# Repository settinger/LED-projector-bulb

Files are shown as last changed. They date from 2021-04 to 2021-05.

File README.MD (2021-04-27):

# LED Replacement for DCA Lamps

In the era of film, the [DCA lamp](https://www.replacementlightbulbs.com/lampdca21v150w.html) was used in dozens of styles of home projector. Nowadays, they are quite hard to come by. And even if you do find a supplier, you'll still end up paying upwards of $100 USD for a single bulb that only lasts around 15 hours! Some people have modified their film projectors to use modern LED illumination, but this usually requires an alternate external power supply and some permanent modifications to the vintage machine. My vision is something much simpler: an LED circuit shaped like the original bulb, a true drop-in replacement!

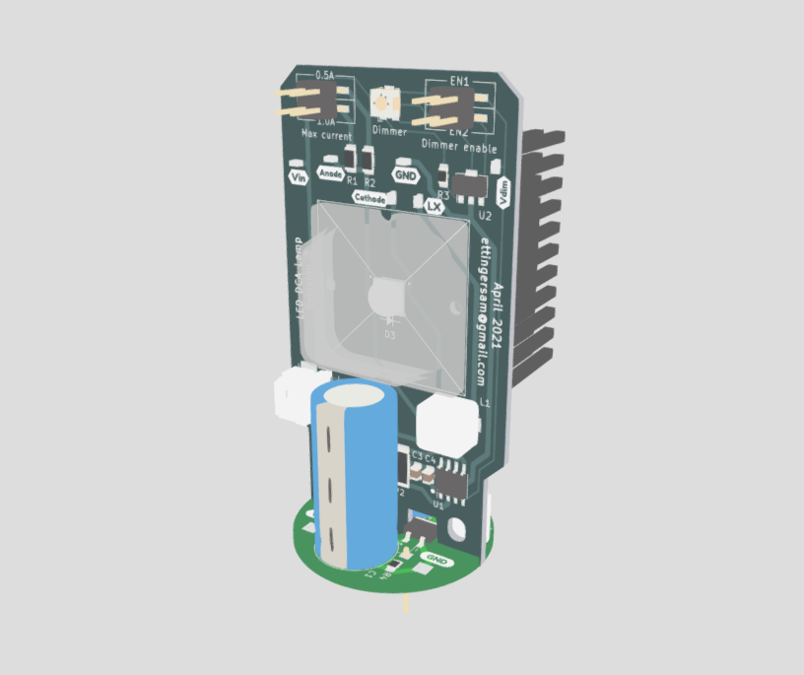
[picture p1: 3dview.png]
3D render of LED bulb
[ <br/>*(Click to go to an interactive 3D viewer)*](https://skfb.ly/onLyB)<br/>

This is most definitely still a work-in-progress. Message me with questions/advice/suggestions/anything!

## Latest version: revision 3 (April 2021)

This is a significant change from the previous two versions. It uses a 19W Cree XHP50.2 (or XHP50) LED, and the whole upright PCB is now a single-layer aluminum-substrate PCB for better thermal management. Screw terminals are used to affix the two boards perpendicularly, and some safety features (2.5A fuse and an optional inrush current limiter) have been added. The bill of materials can be found [over here](/bom/bom.md) or in [this interactive page](/bom/ibom.html).

## Revision 2 (April 2021)
The main change between revisions 1 and 2 is the LED driver itself. I switched from the AL8860 IC to the PAM2863 because the AL8860 is out of stock friggin' EVERYWHERE right now. I also did away with the 15V LDO; why did I even put that on there in the first place? In its place is a tiny 3.3V LDO to power the dimmer controls. This design still uses the same LED module. I did not fix the incorrect light center distance. Instead, I overhauled the PCB to make Revision 3.

## Revision 1 (November 2020)
My first attempt at a DCA replacement. It uses a no-brand 10W LED module that is (was?) prevalent on eBay. The AC-to-DC rectifying capacitors are 16 mm in diameter, and protrude over the edge of the base PCB. This prevented them from sitting properly in my test projector (an Argos Showmaster 750A). Even if it were to fit in the socket, the light center distance on this PCB is a 1/4 inch too high, which is substantial. The dimming circuit did not behave the way I was expecting; at low control voltages the LED would flash on and off around 0.5 Hz, instead of getting dimmer.

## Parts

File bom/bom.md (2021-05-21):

# Bill of Materials
## Revision 3

## Base PCB BOM

| | References | Value | Footprint | Quantity | Digi-Key Part Number | Notes |
|---|---|---|---|---|---|---|
| 1 | R4 | 1 MΩ | 0805 (2012 Metric) | 1 | [RMCF0805JT1M20CT-ND‎](https://www.digikey.com/product-detail/en/RMCF0805JT1M20/RMCF0805JT1M20CT-ND/2418504/) | |
| 2 | JP1 | 0 Ω | 0603 (1608 Metric) | 1 | [36-5110CT-ND‎](https://www.digikey.com/product-detail/en/5110/36-5110CT-ND/5118858/) | Rated for at least 3 A. Do not use if you are using an inrush current limiter (TH1). |
| 3 | C1, C2 | 1000 μF | ⌀ 12.5 mm, 5 mm pitch | 1 | [UHD1V102MHD-ND‎](https://www.digikey.com/product-detail/en/UHD1V102MHD/UHD1V102MHD-ND/2428131/) | Rated for at least 1.5 A ripple current; must be less than 25.4 mm high to accommodate the lens and heatsink. |
| 4 | D1 | Bridge Rectifier | TO-269AA | 1 | [641-1432-1-ND‎](https://www.digikey.com/product-detail/en/CDBHM2100L-HF/641-1432-1-ND/2731390/) | I<sub>F(AV)</sub> ≥ 2 A, V<sub>RRM</sub> ≥ 40 V. |
| 5 | F1 | 2.5 A Slow Blow | 1206 (3216 Metric) | 1 | [507-1895-1-ND‎](https://www.digikey.com/product-detail/en/0685T2500-01/507-1895-1-ND/4968176/) | I've never had to pick a fuse for an AC load before, I have very little confidence in this fuse selection. |
| 6 | LA1 | Lamp base | GX17q | 1 | | It's just four header pins. |
| 7 | J1, J2 | Molex CLIK-Mate 1.50 mm Cable Assembly | Off-board | 0.5 | [WM22838-ND‎](https://www.digikey.com/product-detail/en/0151350203/WM22838-ND/6833464/) | Cut cable assembly in half, solder bare wires to J1 and J2 on base PCB, plug the connector into J3. |
| 8 | H1, H2 | Würth Redcube Screw Terminal | 7.0×4.3 mm | 2 | [732-10897-1-ND](https://www.digikey.com/en/products/detail/w%C3%BCrth-elektronik/7466313R/6643993) | |
| 9 | TH1 | 5 Ω 5 A NTC Thermistor | Off-board | 1 | [495-2100-ND‎](https://www.digikey.com/product-detail/en/B57237S0509M000/495-2100-ND/739855/) | Inrush current limiter, might not be necessary. Do not solder JP1 if you plan to use TH1. |
| 10 | *[no designator]* | M3 bolt, 6mm length | Off-board | 2 | | Attaches upright PCB at terminals H1, H2. |

## Upright PCB BOM

| | References | Value | Footprint | Quantity | Digi-Key Part Number | Notes |
|---|---|---|---|---|---|---|
| 1 | R1 | 0.100 Ω | 1206 (3216 Metric) | 1 | [273-KDV12FR100ETCT-ND‎](https://www.digikey.com/product-detail/en/KDV12FR100ET/273-KDV12FR100ETCT-ND/10476942/) | |
| 2 | R2 | 0.200 Ω | 1206 (3216 Metric) | 1 | [273-KDV12FR200ETCT-ND‎](https://www.digikey.com/product-detail/en/KDV12FR200ET/273-KDV12FR200ETCT-ND/10477106/) | |
| 3 | R3 | 7.5 kΩ | 0805 (2012 Metric) | 1 | [2019-RK73H2ATTD7501FCT-ND‎](https://www.digikey.com/product-detail/en/RK73H2ATTD7501F/2019-RK73H2ATTD7501FCT-ND/10235459/) | |
| 4 | JP2 | 0 Ω | 2512 (6432 Metric) | 1 | [CR2512-J/-000ELFCT-ND‎](https://www.digikey.com/product-detail/en/CR2512-J%2f-000ELF/CR2512-J%2f-000ELFCT-ND/3767855/) | Rated for at least 2 A. |
| 5 | C3, C4 | 10 μF | 0805 (2012 Metric) | 2 | [490-10515-1-ND‎](https://www.digikey.com/product-detail/en/GRM21BR6YA106ME43L/490-10515-1-ND/5026446/) | |
| 6 | C5 | 1 μF | 0805 (2012 Metric) | 1 | [1276-2926-1-ND‎](https://www.digikey.com/product-detail/en/CL21B105KAFNFNE/1276-2926-1-ND/3891012/?itemSeq=362829291) | Optional capacitor to smooth output ripple. |
| 7 | L1 | 47 μH | 7.4×7.0 mm | 1 | [P124172CT-ND‎](https://www.digikey.com/product-detail/en/ETQ-P4M470KFM/P124172CT-ND/9765177/?itemSeq=362633496) | Any value between 33 μH and 120 μH should be fine. |
| 8 | RV1 | 10 kΩ | TC33X | 1 | [TC33X-103ECT-ND‎](https://www.digikey.com/product-detail/en/TC33X-2-103E/TC33X-103ECT-ND/612911/) | |
| 9 | D2 | LED | 2020 (5050 Metric) | 1 | [XHP50B-00-0000-0D0BJ250ECT-ND‎](https://www.digikey.com/product-detail/en/XHP50B-00-0000-0D0BJ250E/XHP50B-00-0000-0D0BJ250ECT-ND/6612923/) (cool white) or [XHP50A-00-0000-0D0HG430HCT-ND‎](https://www.digikey.com/product-detail/en/XHP50A-00-0000-0D0HG430H/XHP50A-00-0000-0D0HG430HCT-ND/5806086/) (warm white) | Cree XHP50 or XHP50.2 White LED. |
| 10 | D3 | Schottky 3 A 40 V | SOD-123W | 1 | [1655-1591-1-ND‎](https://www.digikey.com/product-detail/en/SK34ATR/1655-1591-1-ND/6023036/) | |
| 11 | U1 | PAM2863 | SOIC-8 Exposed Pad | 1 | [PAM2863ECRDICT-ND‎](https://www.digikey.com/product-detail/en/PAM2863ECR/PAM2863ECRDICT-ND/4505228/) | [Datasheet](https://www.diodes.com/assets/Datasheets/PAM2863.pdf) |
| 12 | U2 | AP7381-33Y-13 | SOT-89-3 (TO-243AA)| 1 | [AP7381-33Y-13DICT-ND‎](https://www.digikey.com/product-detail/en/AP7381-33Y-13/AP7381-33Y-13DICT-ND/7914856/) | Ensure the regulator is rated to handle more than 30 V input. |
| 13 | J3 | Molex CLIK-Mate 2-position | 1.50 mm pitch | 1 | [WM14459CT-ND‎](https://www.digikey.com/product-detail/en/5025840260/WM14459CT-ND/6133190/) | The footprint should work for vertical- or horizontal-insert sockets. |
| 14 | J4, J5 | 2x2 SMD Pin Header | SMD 2.52 mm pitch  | 2 | [WM9514-ND‎](https://www.digikey.com/product-detail/en/0015912040/WM9514-ND/3124153/) | |
| 15 | HS1 | Heatsink | 35×35×18 mm | 1 | [HS396-ND‎](https://www.digikey.com/product-detail/en/374724B00032G/HS396-ND/1216400/) | How big should it be? Do I need a fan? |
| 16 | TP1, TP2, TP3, TP4, TP5, TP6 | Test Point | 0603 (1608 Metric) | 6 | [2019-RCUCTECT-ND‎](https://www.digikey.com/product-detail/en/RCUCTE/2019-RCUCTECT-ND/11476593/) | Optional. |
| 17 | LENS1 | LEDiL Lens HB-SQ-W | 25×25 mm | 1 | [711-1589-ND‎](https://www.digikey.com/product-detail/en/C16369_HB-SQ-W/711-1589-ND/9095514/) | Is this necessary? Who knows. |
| 18 | *[no designator]* | 2.54 mm pin header shunts  | Off-board | 4 | [609-861410021H11LF-ND‎](https://www.digikey.com/product-detail/en/861410021H11LF/609-861410021H11LF-ND/4417821/) | Used for setting the max current (J4) and enabling the dimmer function (J5). |

## Combined BOM

| | References | Value | Footprint | Quantity | Digi-Key Part Number | Notes |
|---|---|---|---|---|---|---|
| 1 | R1 | 0.100 Ω | 1206 (3216 Metric) | 1 | [273-KDV12FR100ETCT-ND‎](https://www.digikey.com/product-detail/en/KDV12FR100ET/273-KDV12FR100ETCT-ND/10476942/) | |
| 2 | R2 | 0.200 Ω | 1206 (3216 Metric) | 1 | [273-KDV12FR200ETCT-ND‎](https://www.digikey.com/product-detail/en/KDV12FR200ET/273-KDV12FR200ETCT-ND/10477106/) | |
| 3 | R3 | 7.5 kΩ | 0805 (2012 Metric) | 1 | [2019-RK73H2ATTD7501FCT-ND‎](https://www.digikey.com/product-detail/en/RK73H2ATTD7501F/2019-RK73H2ATTD7501FCT-ND/10235459/) | |
| 4 | R4 | 1 MΩ | 0805 (2012 Metric) | 1 | [RMCF0805JT1M20CT-ND‎](https://www.digikey.com/product-detail/en/RMCF0805JT1M20/RMCF0805JT1M20CT-ND/2418504/) | |
| 5 | JP1 | 0 Ω | 0603 (1608 Metric) | 1 | [36-5110CT-ND‎](https://www.digikey.com/product-detail/en/5110/36-5110CT-ND/5118858/) | Rated for at least 3 A. Do not use if you are using an inrush current limiter (TH1). |
| 6 | JP2 | 0 Ω | 2512 (6432 Metric) | 1 | [CR2512-J/-000ELFCT-ND‎](https://www.digikey.com/product-detail/en/CR2512-J%2f-000ELF/CR2512-J%2f-000ELFCT-ND/3767855/) | Rated for at least 2 A. |
| 7 | C1, C2 | 1000 μF | ⌀ 12.5 mm, 5 mm pitch | 1 | [UHD1V102MHD-ND‎](https://www.digikey.com/product-detail/en/UHD1V102MHD/UHD1V102MHD-ND/2428131/) | Rated for at least 1.5 A ripple current; must be less than 25.4 mm high to accommodate the lens and heatsink. |
| 8 | C3, C4 | 10 μF | 0805 (2012 Metric) | 2 | [490-10515-1-ND‎](https://www.digikey.com/product-detail/en/GRM21BR6YA106ME43L/490-10515-1-ND/5026446/) | |
| 9 | C5 | 1 μF | 0805 (2012 Metric) | 1 | [1276-2926-1-ND‎](https://www.digikey.com/product-detail/en/CL21B105KAFNFNE/1276-2926-1-ND/3891012/?itemSeq=362829291) | Optional capacitor to smooth output ripple. |
| 10 | L1 | 47 μH | 7.4×7.0 mm | 1 | [P124172CT-ND‎](https://www.digikey.com/product-detail/en/ETQ-P4M470KFM/P124172CT-ND/9765177/?itemSeq=362633496) | Any value between 33 μH and 120 μH should be fine. |
| 11 | RV1 | 10 kΩ | TC33X | 1 | [TC33X-103ECT-ND‎](https://www.digikey.com/product-detail/en/TC33X-2-103E/TC33X-103ECT-ND/612911/) | |
| 12 | D1 | Bridge Rectifier | TO-269AA | 1 | [641-1432-1-ND‎](https://www.digikey.com/product-detail/en/CDBHM2100L-HF/641-1432-1-ND/2731390/) | I<sub>F(AV)</sub> ≥ 2 A, V<sub>RRM</sub> ≥ 40 V. |
| 13 | D2 | LED | 2020 (5050 Metric) | 1 | [XHP50B-00-0000-0D0BJ250ECT-ND‎](https://www.digikey.com/product-detail/en/XHP50B-00-0000-0D0BJ250E/XHP50B-00-0000-0D0BJ250ECT-ND/6612923/) (cool white) or [XHP50A-00-0000-0D0HG430HCT-ND‎](https://www.digikey.com/product-detail/en/XHP50A-00-0000-0D0HG430H/XHP50A-00-0000-0D0HG430HCT-ND/5806086/) (warm white) | Cree XHP50 or XHP50.2 White LED. |
| 14 | D3 | Schottky 3 A 40 V | SOD-123W | 1 | [1655-1591-1-ND‎](https://www.digikey.com/product-detail/en/SK34ATR/1655-1591-1-ND/6023036/) | |
| 15 | F1 | 2.5 A Slow Blow | 1206 (3216 Metric) | 1 | [507-1895-1-ND‎](https://www.digikey.com/product-detail/en/0685T2500-01/507-1895-1-ND/4968176/) | I've never had to pick a fuse for an AC load before, I have very little confidence in this fuse selection. |
| 16 | U1 | PAM2863 | SOIC-8 Exposed Pad | 1 | [PAM2863ECRDICT-ND‎](https://www.digikey.com/product-detail/en/PAM2863ECR/PAM2863ECRDICT-ND/4505228/) | [Datasheet](https://www.diodes.com/assets/Datasheets/PAM2863.pdf) |
| 17 | U2 | AP7381-33Y-13 | SOT-89-3 (TO-243AA)| 1 | [AP7381-33Y-13DICT-ND‎](https://www.digikey.com/product-detail/en/AP7381-33Y-13/AP7381-33Y-13DICT-ND/7914856/) | Ensure the regulator is rated to handle more than 30 V input. |
| 18 | LA1 | Lamp base | GX17q | 1 | | It's just four header pins. |
| 19 | J1, J2 | Molex CLIK-Mate 1.50 mm Cable Assembly | Off-board | 0.5 | [WM22838-ND‎](https://www.digikey.com/product-detail/en/0151350203/WM22838-ND/6833464/) | Cut cable assembly in half, solder bare wires to J1 and J2 on base PCB, plug the connector into J3. |
| 20 | J3 | Molex CLIK-Mate 1.50 mm 2-position socket | 8.5×8.0 mm | 1 | [WM14459CT-ND‎](https://www.digikey.com/product-detail/en/5025840260/WM14459CT-ND/6133190/) | The footprint should work for vertical- or horizontal-insert sockets. |
| 21 | J4, J5 | 2x2 SMD Pin Header | SMD 2.52 mm pitch  | 2 | [WM9514-ND‎](https://www.digikey.com/product-detail/en/0015912040/WM9514-ND/3124153/) | |
| 22 | H1, H2 | Würth Redcube Screw Terminal | 7.0×4.3 mm | 2 | [732-10897-1-ND](https://www.digikey.com/en/products/detail/w%C3%BCrth-elektronik/7466313R/6643993) | |
| 23 | HS1 | Heatsink | 35×35×18 mm | 1 | [HS396-ND‎](https://www.digikey.com/product-detail/en/374724B00032G/HS396-ND/1216400/) | How big should it be? Do I need a fan? |
| 24 | TP1, TP2, TP3, TP4, TP5, TP6 | Test Point | 0603 (1608 Metric) | 6 | [2019-RCUCTECT-ND‎](https://www.digikey.com/product-detail/en/RCUCTE/2019-RCUCTECT-ND/11476593/) | Optional. |
| 25 | LENS1 | LEDiL Lens HB-SQ-W | 25×25 mm | 1 | [711-1589-ND‎](https://www.digikey.com/product-detail/en/C16369_HB-SQ-W/711-1589-ND/9095514/) | Is this necessary? Who knows. |
| 26 | TH1 | 5 Ω 5 A NTC Thermistor | Off-board | 1 | [495-2100-ND‎](https://www.digikey.com/product-detail/en/B57237S0509M000/495-2100-ND/739855/) | Inrush current limiter, might not be necessary. Do not solder JP1 if you plan to use TH1. |
| 27 | *[no designator]* | M3 bolt, 6 mm length | Off-board | 2 | | Attaches upright PCB at terminals H1, H2. |
| 28 | *[no designator]* | 2.54 mm pin header shunts  | Off-board | 4 | [609-861410021H11LF-ND‎](https://www.digikey.com/product-detail/en/861410021H11LF/609-861410021H11LF-ND/4417821/) | Used for setting the max current (J4) and enabling the dimmer function (J5). |

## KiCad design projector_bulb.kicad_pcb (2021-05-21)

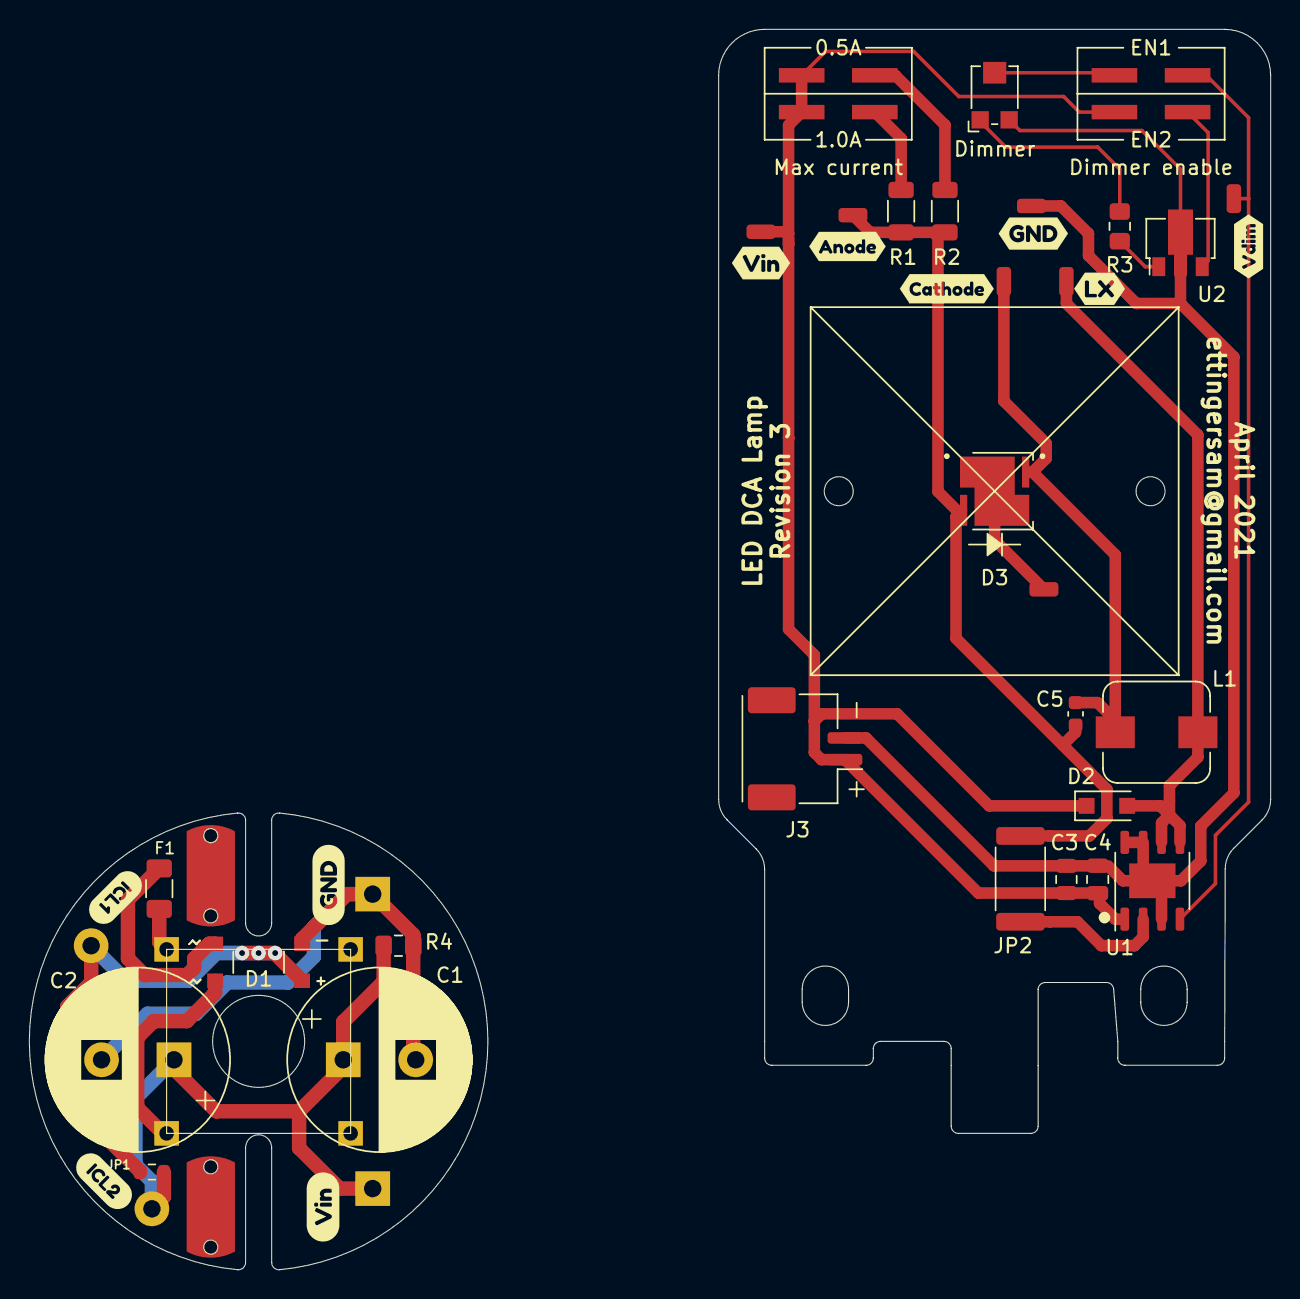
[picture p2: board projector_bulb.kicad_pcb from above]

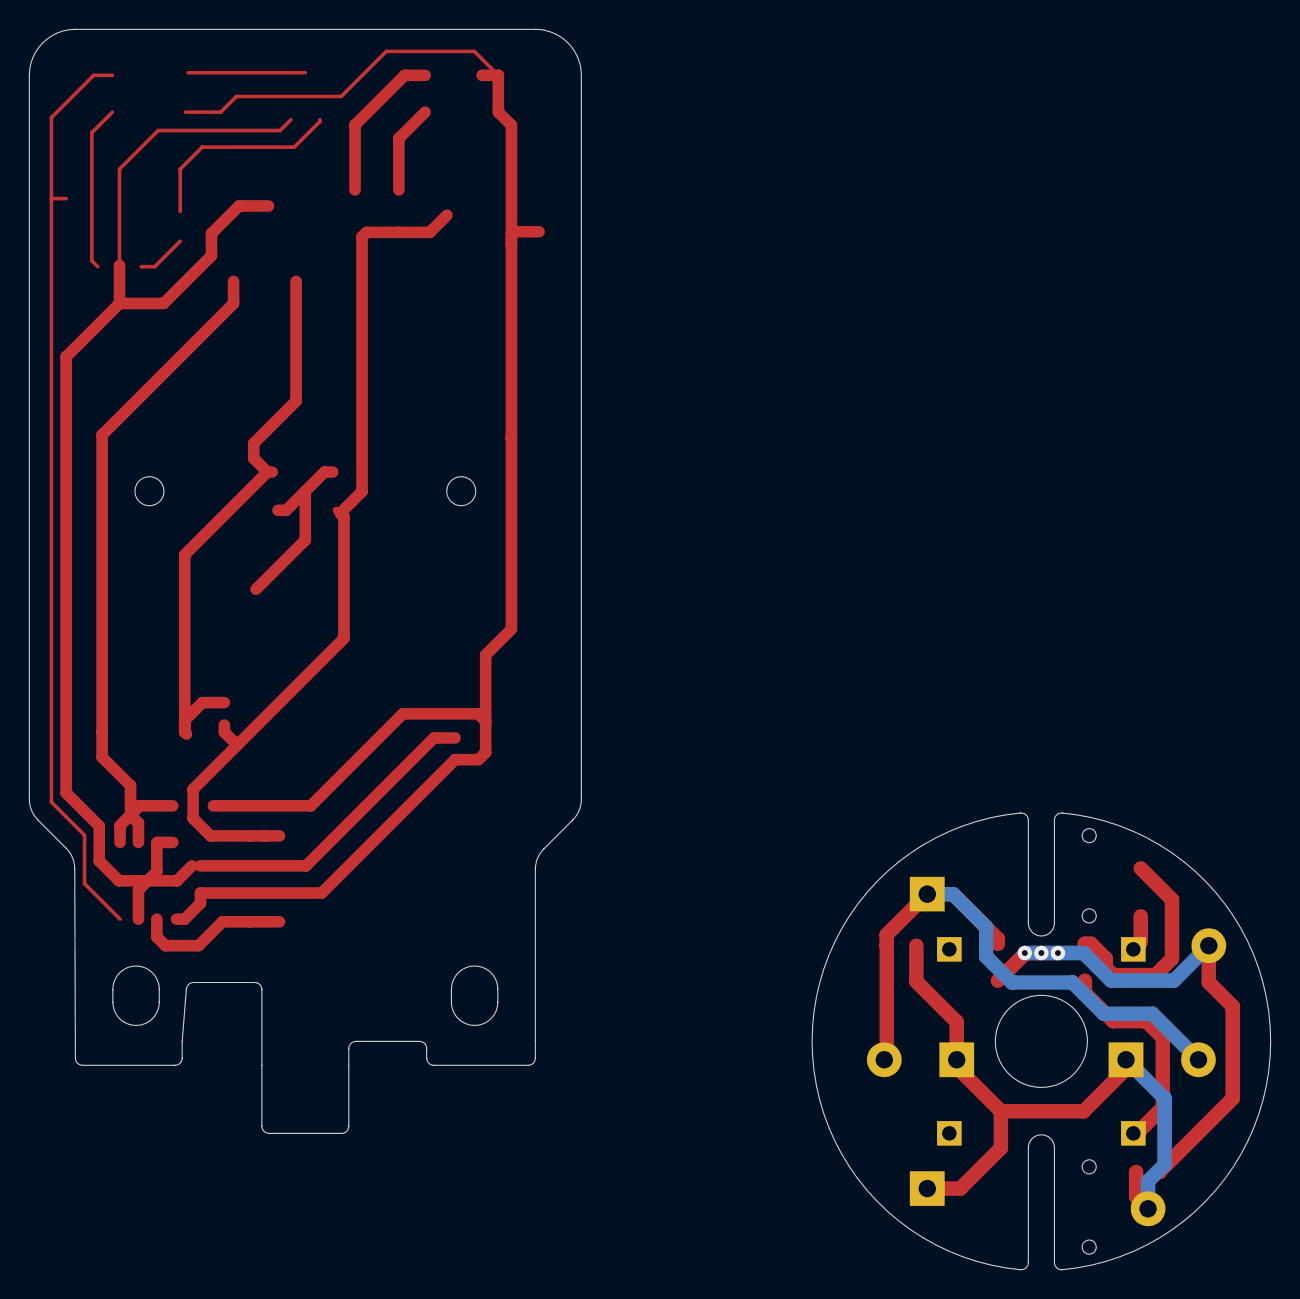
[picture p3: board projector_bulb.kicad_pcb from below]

Board: 2 copper layers, 85.7 x 85.6 mm, 47 parts (2 on the bottom side), 20 nets.

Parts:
C1, C2: 1000μ; CP_Radial_D12.5mm_P5.00mm
C3, C4: 10μ; C_0805_2012Metric
C5: 1μ; C_0603_1608Metric
D1: Bridge Rectifier; Diode_Bridge_Comchip_2A
D2: Schottky; D_SOD-123F
D3: LED; LED_Cree-XHP50_12V
F1: Fuse; Fuse_1206_3216Metric
H1, H2: MountingHole; wuerth_7466313R
HS1: Heatsink; Heatsink_35x35x18mm
J1: to_upright_+; TestPoint_THTPad_3.0x3.0mm_Drill1.5mm
J2: to_upright_-; TestPoint_THTPad_3.0x3.0mm_Drill1.5mm
J3: to_base; Molex_CLIK-Mate_505405-0270_1x02-1MP_P1.50mm_Vertical
J4, J5: Conn_02x02_Odd_Even; PinHeader_2x02_P2.54mm_Vertical_SMD
JP1: ICL Bypass; R_0603_1608Metric
JP2: Jumper_NC_Small; R_2512_6332Metric
L1: 47μ; panasonic_PCC-M0748M
LA1: Lamp; GX17q
LENS1: Lens; LENS_LEDIL_CA16370_HB-SQ-W
R1: 0.200; R_1206_3216Metric
R2: 0.100; R_1206_3216Metric
R3: 7.5k; R_0805_2012Metric_Pad1.15x1.40mm_HandSolder
R4: 1M; R_0805_2012Metric_Pad1.15x1.40mm_HandSolder
RV1: 10k; Potentiometer_Bourns_TC33X_Vertical
TH1: Thermistor_NTC; RV_Disc_D21.5mm_W4.3mm_P10mm
TP1, TP2, TP3, TP4, TP5, TP6, TP7: TestPoint; Test_Point_0603
U1: PAM2863; HTSOP-8-1EP_3.9x4.9mm_P1.27mm_EP2.4x3.2mm
U2: AP7381-33Y; SOT-89-3
svg2mod, svg2mod#2, svg2mod#3, svg2mod#4, svg2mod#5, svg2mod#6, svg2mod#7, svg2mod#8, svg2mod#9, svg2mod#10: G***; label

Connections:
DIMMING: J5.1, TP4.1, U1.4
GND_BASE: C1.2, C2.2, D1.2, J2.1, R4.2
GND_UPRIGHT: C3.1, C4.1, J3.2, RV1.3, TP2.1, U1.3, U1.7, U1.8, U1.9, U2.2
unnamed: C5.1, D3.1, L1.1, TP6.1
unnamed: C5.2, D3.2, JP2.2, R1.2, R2.2, TP5.1
unnamed: D1.1, JP1.1, TH1.2
unnamed: D1.3, F1.1
unnamed: D1.4, LA1.1
unnamed: D2.2, L1.2, TP3.1, U1.5, U1.6
unnamed: D3.3, TP7.1
unnamed: F1.2, LA1.2
unnamed: J4.2, R2.1
unnamed: J4.4, R1.1
unnamed: J5.2, RV1.2
unnamed: J5.4, U2.3
unnamed: JP2.1, U1.2
unnamed: R3.1, RV1.1
unnamed: R3.2, U2.1
VIN_BASE: C1.1, C2.1, J1.1, JP1.2, R4.1, TH1.1
VIN_UPRIGHT: C3.2, C4.2, D2.1, J3.1, J4.1, J4.3, J5.3, TP1.1, U1.1

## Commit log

2021-04-16 Revision 2, still needs documentation and things
    [projector_bulb.kicad_pcb, projector_bulb.sch, projector_bulb_base.kicad_pcb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]
2021-04-20 Much progress on Aluminum PCB
    [projector_bulb.kicad_pcb, projector_bulb.sch, projector_bulb_base.kicad_pcb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]
2021-04-21 More changes, about to add some safety circuitry
    [projector_bulb.kicad_pcb, projector_bulb.sch]
2021-04-21 Cleaned up schematic, working on documentation next
    [projector_bulb.kicad_pcb, projector_bulb.sch]
2021-04-24 Add test points, replaced some expensive components with cheaper alternatives
    [projector_bulb.kicad_pcb, projector_bulb.sch, projector_bulb_base.kicad_pcb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]
2021-04-25 Making edits
    [projector_bulb.kicad_pcb, projector_bulb.sch]
2021-04-25 Routing optimizations
    [projector_bulb.kicad_pcb, projector_bulb.sch]
2021-04-26 About to attempt KiCad StepUp, wish me luck
    [projector_bulb.kicad_pcb, projector_bulb.sch]
2021-04-26 Added fillets after much blood sweat and tears
    [projector_bulb.kicad_pcb]
2021-04-27 BOM and readme updated
    [projector_bulb.kicad_pcb, projector_bulb.sch, projector_bulb_base.kicad_pcb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]
2021-04-29 Locking in revision 3 finally; moved the optional ICL to a place where I can treat it like a test point
    [projector_bulb.kicad_pcb, projector_bulb.sch, projector_bulb_base.kicad_pcb]
2021-05-19 Add test point for thermal pad of LED
    [projector_bulb.kicad_pcb, projector_bulb.sch, projector_bulb_base.kicad_pcb]
2021-05-21 Changed all references of 7466310R to 7466313R
    [projector_bulb.kicad_pcb, projector_bulb.sch, projector_bulb_base.kicad_pcb]
2021-05-21 Changed all references of 7466310R to 7466313R (for real this time)
    [projector_bulb.kicad_pcb, projector_bulb_base.kicad_pcb]
